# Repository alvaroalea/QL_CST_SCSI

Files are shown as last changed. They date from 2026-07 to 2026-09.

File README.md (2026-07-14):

# CST SCSI/FLOPPY CONTROLLER for Sinclar QL

A clone of the CST's Floppy + hardisc Interface for the Sinclair QL

# WARNING: DO NOT USE THIS PROJECT IS NOT TESTED AND MISSING THINGS

An evolution of the CST V4 Floppy interface with the incorporation of SCSI Controller.

The SCSI was limited only to a especific HDD model: Rodine RO652 20Mb, an UK Manufactured HDD that was also used on Macintosh SE

Later this interface will be use as a base for the Thor 20 Computer SCSI interface.

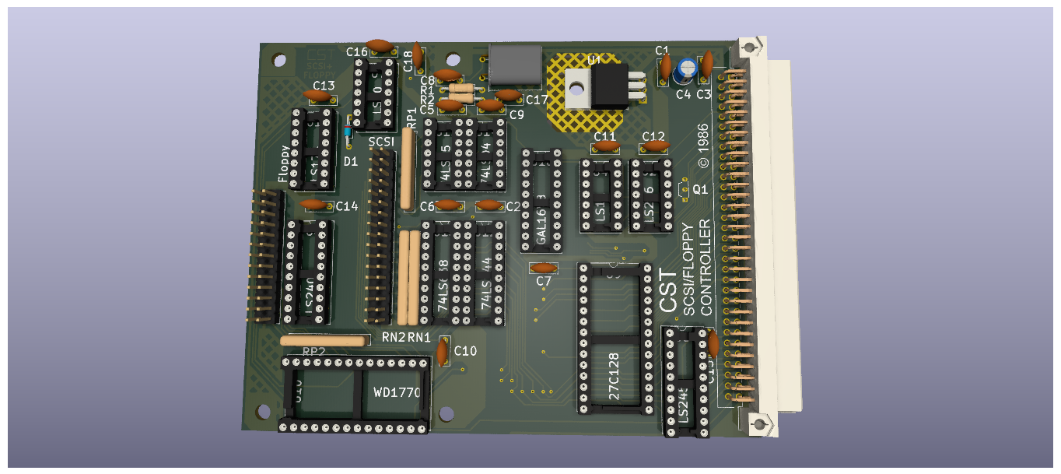
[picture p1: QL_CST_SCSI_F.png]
 

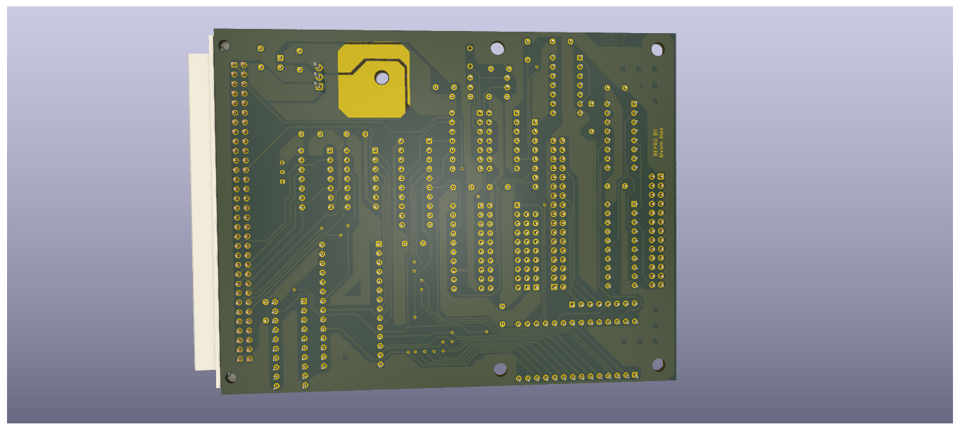
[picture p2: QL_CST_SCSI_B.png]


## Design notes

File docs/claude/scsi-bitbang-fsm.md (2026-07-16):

# Máquina de estados SCSI-1 para bitbanging (iniciador único, sin ATN)

## 1. Fases del bus (nivel alto)

El iniciador reconoce la fase leyendo las líneas **C/D, I/O, MSG** que el
target pone estables justo antes/durante REQ. No hay arbitraje porque eres
el único iniciador en el bus.

```mermaid
stateDiagram-v2
    [*] --> BUS_FREE

    BUS_FREE --> SELECTION: Iniciador quiere mandar comando

    state SELECTION {
        [*] --> SEL_ASSERT
        SEL_ASSERT --> SEL_WAIT_BSY: Pon ID_iniciador+ID_target en DB,\nafirma SEL (sin ATN)
        SEL_WAIT_BSY --> SEL_OK: Target afirma BSY (timeout ~250ms)
        SEL_WAIT_BSY --> SEL_TIMEOUT: No responde
    }
    SELECTION --> BUS_FREE: SEL_TIMEOUT (disco no responde)
    SELECTION --> COMMAND: SEL_OK\n(suelta SEL cuando BSY activo)

    COMMAND --> COMMAND: Handshake REQ/ACK\n(6 bytes del CDB, C/D=1,I/O=0,MSG=0)

    COMMAND --> DATA_IN: si comando de lectura,\ntarget cambia C/D=0,I/O=1
    COMMAND --> DATA_OUT: si comando de escritura,\ntarget cambia C/D=0,I/O=0
    COMMAND --> STATUS: si comando sin datos\n(TEST UNIT READY, START STOP)
    COMMAND --> STATUS: si target reporta error\n(CHECK CONDITION inmediato)

    DATA_IN --> DATA_IN: Handshake REQ/ACK\n(N bytes, target->iniciador)
    DATA_OUT --> DATA_OUT: Handshake REQ/ACK\n(N bytes, iniciador->target)

    DATA_IN --> STATUS: Todos los bytes transferidos\n(C/D=1,I/O=1,MSG=0)
    DATA_OUT --> STATUS: Todos los bytes transferidos

    STATUS --> STATUS: Handshake REQ/ACK\n(1 byte: GOOD=0x00 / CHECK_COND=0x02)

    STATUS --> MSG_IN: target cambia\nC/D=1,I/O=1,MSG=1

    MSG_IN --> MSG_IN: Handshake REQ/ACK\n(1 byte: COMMAND COMPLETE=0x00)

    MSG_IN --> BUS_FREE: Target suelta BSY\n(fin de comando)

    STATUS --> REQUEST_SENSE_NEEDED: si status fue CHECK_CONDITION
    REQUEST_SENSE_NEEDED --> BUS_FREE: (tras MSG_IN)\nlanzar REQUEST SENSE\ncomo nuevo comando
```

**Notas clave:**
- Sin ATN afirmado en SELECTION, el target no espera MESSAGE OUT (te ahorras esa fase).
- El iniciador **nunca decide la fase**: solo la lee de C/D/I-O/MSG y actúa en consecuencia. Si el firmware ve una fase inesperada, debe abortar (soltar el bus, hacer RST si hace falta).
- `REQUEST_SENSE_NEEDED`: tras cualquier `CHECK CONDITION`, el siguiente comando *debe* ser `REQUEST SENSE` o el disco se queda "atascado" en esa condición de error.

---

## 2. Handshake REQ/ACK (el que se ejecuta por cada byte, en cualquier fase)

Es un protocolo **asíncrono** — no hay reloj, todo se sincroniza a mano con
REQ/ACK. Es idéntico en estructura para las 4 fases de transferencia
(COMMAND, DATA, STATUS, MESSAGE IN); solo cambia quién conduce el bus de
datos.

### 2a. Target → Iniciador (DATA IN, STATUS, MESSAGE IN)

```mermaid
stateDiagram-v2
    [*] --> WAIT_REQ_HIGH
    WAIT_REQ_HIGH --> READ_DATA: REQ afirmado por target\n(target ya puso byte válido en DB)
    READ_DATA --> ASSERT_ACK: Iniciador lee DB\n(digitalRead x8, o puerto entero)
    ASSERT_ACK --> WAIT_REQ_LOW: Iniciador afirma ACK
    WAIT_REQ_LOW --> DEASSERT_ACK: Target ve ACK,\ndeasfirma REQ (retira dato)
    DEASSERT_ACK --> WAIT_REQ_HIGH: Iniciador deasfirma ACK\n(byte completo, incrementa contador)
    WAIT_REQ_HIGH --> [*]: si contador de bytes\nde la fase = 0 -> fase terminada
```

### 2b. Iniciador → Target (COMMAND, DATA OUT)

```mermaid
stateDiagram-v2
    [*] --> WAIT_REQ_HIGH
    WAIT_REQ_HIGH --> DRIVE_DATA: REQ afirmado por target\n(target listo para recibir)
    DRIVE_DATA --> ASSERT_ACK: Iniciador pone byte en DB\n(configura puerto como salida)
    ASSERT_ACK --> WAIT_REQ_LOW: Iniciador afirma ACK
    WAIT_REQ_LOW --> RELEASE_DATA: Target latchea el dato,\ndeasfirma REQ
    RELEASE_DATA --> DEASSERT_ACK: Iniciador suelta DB\n(vuelve a alta impedancia / entrada)
    DEASSERT_ACK --> WAIT_REQ_HIGH: Iniciador deasfirma ACK
    WAIT_REQ_HIGH --> [*]: si contador de bytes\nde la fase = 0 -> fase terminada
```

**Timing crítico a respetar en el bitbang (SCSI-1 async, cable corto):**
- Data setup time antes de ACK: ≥ 90 ns (en la práctica, con GPIO de 8 bits a través de un pin-change, ni lo notarás — el cuello de botella real es tu velocidad de toggling de pines).
- Bus settle / skew entre líneas de datos: ≥ 10 ns.
- Ninguno de estos plazos es alcanzable "por accidente" en un micro de 8 bits a decenas de MHz sin cuidado — en la práctica te sobra margen, el problema real suele ser la *capacitancia del cable* si no usas buffers (74LS641 o similar) entre el micro y el bus SCSI de 5V.

---

## 3. Pseudocódigo del bucle central

```c
uint8_t scsi_handshake_in(void) {           // target -> iniciador
    while (!REQ_asserted());                 // espera REQ
    uint8_t byte = read_data_bus();
    ACK_assert();
    while (REQ_asserted());                  // espera a que target suelte REQ
    ACK_deassert();
    return byte;
}

void scsi_handshake_out(uint8_t byte) {      // iniciador -> target
    while (!REQ_asserted());
    drive_data_bus(byte);
    ACK_assert();
    while (REQ_asserted());
    release_data_bus();
    ACK_deassert();
}
```

Con estas dos funciones (`scsi_handshake_in` / `scsi_handshake_out`) y la
máquina de fases de arriba, ya tienes toda la lógica de bajo nivel que
necesita READ(6)/WRITE(6)/STATUS/MESSAGE — cada fase es solo "llamar N
veces a la función correcta".

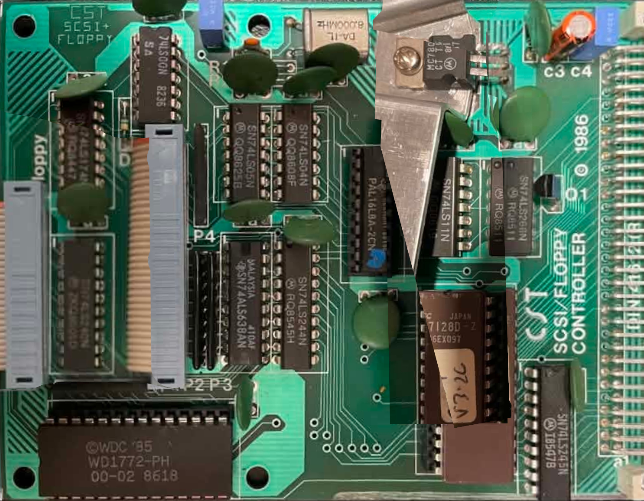
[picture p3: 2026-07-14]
docs/comp.jpg

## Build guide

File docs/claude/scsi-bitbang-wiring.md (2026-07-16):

# Mapeo físico y esquema eléctrico: Arduino Leonardo ↔ 74LS638 / 74LS04 / 74LS06 ↔ SCSI-1 (RO652A)

## 1. Reparto de chips

- **U1 — 74LS638:** bus de datos DB0-DB7 (el único bidireccional).
- **U2 — 74LS04** (inversor hex, push-pull estándar, 6 puertas): las 5
  señales que solo *lees* del SCSI: BSY, REQ, C/D, I/O, MSG. Sobra
  1 puerta libre. Push-pull es válido aquí porque la salida de cada
  puerta solo alimenta una entrada de alta impedancia del Arduino —
  nadie más conduce esa línea, así que no hay competencia eléctrica
  posible. De hecho es preferible al 74LS05: sin pull-ups externos y
  con flancos más rápidos y limpios, mejor para la línea REQ que
  dispara la interrupción.
- **U3 — 74LS06** (inversor hex, colector abierto, 40 mA, 6 puertas):
  las 3 señales que solo *escribes* hacia el SCSI: SEL, ACK, RST.
  Sobran 3 puertas libres.

Al ser inversores simples (sin DIR/OE), aquí no hay nada que
configurar por cableado: cada señal SCSI pasa por una puerta y ya
está.

⚠️ La regla que **no** se puede relajar es la del lado de salida
(U3): ahí sí tiene que ser colector abierto obligatoriamente, porque
esa puerta compite eléctricamente con el pull-up del terminador del
bus (y potencialmente con el propio disco). Un push-pull ahí forzaría
la línea y podría dañar el chip o el disco.

Polaridad resultante (igual criterio que con el 638): como ambos
chips son inversores y las líneas SCSI son activas-en-bajo, en el
lado Arduino "asertado" siempre se lee/escribe como **HIGH** — misma
convención que ya usa el pseudocódigo de la ISR.

**Nota sobre paridad (DBP):** para mantenerlo simple, este diseño **no
implementa el bit de paridad**. El RO652A permite en muchos casos
desactivar la comprobación de paridad por configuración; si tu unidad
concreta la exige, tendrías que añadir un noveno canal (usar un canal
libre de U1 con un XOR de 8 entradas externo, o un segundo 638 de un
solo canal). Verifícalo en la práctica: si el drive devuelve
`CHECK CONDITION` con `PARITY ERROR` en el sense, hay que añadirlo.

---

## 2. Cableado de cada chip

### U1 — 74LS638 (datos, 20 pines)

```
              74LS638 (U1 - DATA, DIR dinámico)
        +--------------------------------+
   DIR--|1                             20|--VCC (+5V)
 SCSI DB0--|2  A1                    B1  19|--Arduino DATA0
 SCSI DB1--|3  A2                    B2  18|--Arduino DATA1
 SCSI DB2--|4  A3                    B3  17|--Arduino DATA2
 SCSI DB3--|5  A4                    B4  16|--Arduino DATA3
 SCSI DB4--|6  A5                    B5  15|--Arduino DATA4
 SCSI DB5--|7  A6                    B6  14|--Arduino DATA5
 SCSI DB6--|8  A7                    B7  13|--Arduino DATA6
 SCSI DB7--|9  A8                    B8  12|--Arduino DATA7
       GND--|10                       OE 11|--GND (siempre habilitado)
        +--------------------------------+
```

### U2 — 74LS04 (entradas, 14 pines, push-pull)

Pinout estándar de la familia 74LSx4/x5/x6 (idéntico al 7404):

```
              74LS04 (U2 - CONTROL-IN)
        +----------------+
   BSY--|1  1A      1Y  2|--> Arduino D10
   REQ--|3  2A      2Y  4|--> Arduino D0   (INT0)
   C/D--|5  3A      3Y  6|--> Arduino A0
   GND--|7               |
   MSG--|9  4A      4Y  8|--> Arduino D13
   I/O--|11 5A      5Y 10|--> Arduino A1
        |   6A      6Y 12|--  libre (spare)
        |13             14|--VCC (+5V)
        +----------------+
```

(Numeración de pines: 1A/1Y=1,2 · 2A/2Y=3,4 · 3A/3Y=5,6 · GND=7 ·
4Y/4A=8,9 · 5Y/5A=10,11 · 6Y/6A=12,13 · VCC=14.)

**Sin pull-ups necesarios:** al ser push-pull, cada salida de U2 ya
conduce activamente tanto a HIGH como a LOW — no hace falta
resistencia externa ni `INPUT_PULLUP` en el Arduino. En firmware, usa
simplemente:
```c
pinMode(PIN_BSY, INPUT);
pinMode(PIN_REQ, INPUT);
pinMode(PIN_CD,  INPUT);
pinMode(PIN_MSG, INPUT);
pinMode(PIN_IO,  INPUT);
```

### U3 — 74LS06 (salidas, 14 pines, colector abierto, 40 mA)

Mismo pinout físico que el 74LS04 (familia idéntica):

```
              74LS06 (U3 - CONTROL-OUT)
        +----------------+
   SEL--|1  1A      1Y  2|--< Arduino A2
   ACK--|3  2A      2Y  4|--< Arduino D11
   RST--|5  3A      3Y  6|--< Arduino D12
   GND--|7               |
        |9  4A      4Y  8|--  libre (spare)
        |11 5A      5Y 10|--  libre (spare)
        |   6A      6Y 12|--  libre (spare)
        |13             14|--VCC (+5V)
        +----------------+
```

Aquí NO hace falta pull-up en ningún lado: el lado SCSI (pines 1,3,5)
ya está tirado a +5V por el terminador del bus, y el lado Arduino
(pines 2,4,6) lo maneja el propio Arduino en push-pull normal, sin
necesitar resistencia.

**Desacoplo:** un condensador cerámico de 100 nF entre VCC y GND lo más
cerca posible de cada chip (pines 20/10), imprescindible en los tres.

---

## 3. Terminación del bus SCSI

El RO652A trae **packs de resistencias terminadoras** en la propia
placa (se ve en la serigrafía de la hoja de specs). SCSI exige
terminación en **ambos extremos físicos** del bus:

- **Extremo del disco:** deja puesto (o vuelve a poner) su pack
  terminador — el RO652 casi siempre se vende con el jumper/pack de
  terminación instalado de fábrica al ser normalmente el único
  dispositivo interno de un Mac/PC de la época.
- **Extremo del Arduino (tu "host adapter"):** necesitas añadir tú un
  terminador pasivo, típicamente un pack SIP de 220 Ω a TERMPWR (+5V)
  y 330 Ω a GND por cada línea de señal (18 líneas: 8 datos + paridad
  + 9 de control). Existen packs comerciales listos (p.ej.
  "9-line SCSI terminator resistor pack").
- **TERMPWR (pin 26):** alguien tiene que alimentarlo con +5V a través
  de un diodo (típicamente 1N5817) y un fusible/polyfuse de ~0.5-1A.
  Si el disco ya lo suministra (frecuente en unidades con terminador
  activo de fábrica), no hace falta que lo hagas también desde el
  Arduino — comprueba con un multímetro si el pin 26 ya tiene +5V
  antes de conectar tu propia fuente, para no pelear dos fuentes entre sí.

Dado que a las velocidades async de bitbang y con un cable corto
punto-a-punto el margen es muy generoso, un terminador algo
imperfecto probablemente "funcione" en pruebas de banco — pero seguir
la terminación en ambos extremos evita reflejos que pueden manifestarse
como bytes corruptos intermitentes, difíciles de diagnosticar.

---

## 4. Mapeo de pines: Arduino Leonardo ↔ 74LS638 ↔ conector SCSI-1 (50 pin IDC)

El RO652A es un drive interno con conector de 50 pines (2×25, paso
0.1"). Pinout estándar SCSI-1 de un solo extremo (single-ended):

| Pin | Señal | Pin | Señal |
|-----|---|-----|---|
| 1 | GND | 2 | -DB0  |
| 3 | GND | 4 | -DB1  |
| 5 | GND | 6 | -DB2  |
| 7 | GND | 8 | -DB3  |
| 9 | GND | 10  | -DB4  |
| 11  | GND | 12  | -DB5  |
| 13  | GND | 14  | -DB6  |
| 15  | GND | 16  | -DB7  |
| 17  | GND | 18  | -DBP (paridad) |
| 19  | GND | 20  | GND |
| 21  | GND | 22  | GND |
| 23  | reservado | 24 | reservado |
| 25  | abierto (no usar) | 26 | TERMPWR (+5V) |
| 27  | reservado | 28 | reservado |
| 29  | GND | 30  | GND |
| 31  | GND | 32  | -ATN  |
| 33  | GND | 34  | GND |
| 35  | GND | 36  | -BSY  |
| 37  | GND | 38  | -ACK  |
| 39  | GND | 40  | -RST  |
| 41  | GND | 42  | -MSG  |
| 43  | GND | 44  | -C/D  |
| 45  | GND | 46  | -REQ  |
| 47  | GND | 48  | -I/O  |
| 49  | GND | 50  | -SEL  |

Todas las señales son activas-en-bajo (negative-true). Los pines
impares son mayoritariamente GND — esto es intencional en el diseño
del cable: cada línea de señal va emparejada con un retorno de tierra
adyacente para reducir diafonía/reflejos.

### Tabla de conexión completa

| Señal SCSI | Pin conector | Chip / puerta | Pin Arduino Leonardo | Notas |
|---|---|---|---|---|
| DB0 | 2  | U1.A1 / U1.B1 | D2  | Bus de datos |
| DB1 | 4  | U1.A2 / U1.B2 | D3  | |
| DB2 | 6  | U1.A3 / U1.B3 | D4  | |
| DB3 | 8  | U1.A4 / U1.B4 | D5  | |
| DB4 | 10 | U1.A5 / U1.B5 | D6  | |
| DB5 | 12 | U1.A6 / U1.B6 | D7  | |
| DB6 | 14 | U1.A7 / U1.B7 | D8  | |
| DB7 | 16 | U1.A8 / U1.B8 | D9  | |
| DBP | 18 | — | — | no implementada (ver nota de paridad) |
| BSY | 36 | U2 (74LS04) gate 1 | D10 | solo lectura |
| ACK | 38 | U3 (74LS06) gate 1 | D11 | solo escritura |
| RST | 40 | U3 (74LS06) gate 2 | D12 | solo escritura |
| MSG | 42 | U2 (74LS04) gate 4 | D13 | solo lectura |
| C/D | 44 | U2 (74LS04) gate 3 | A0  | solo lectura |
| REQ | 46 | U2 (74LS04) gate 2 | **D0** (INT0) | **interrupción**, flancos limpios sin pull-up |
| I/O | 48 | U2 (74LS04) gate 5 | A1  | solo lectura |
| SEL | 50 | U3 (74LS06) gate 3 | A2  | solo escritura |
| U1.DIR | — | — | A3  | control dinámico dirección datos |

**Por qué REQ en D0:** en el Leonardo (ATmega32u4), las únicas líneas
con interrupción externa "de verdad" (`INT`) son D0, D1, D2, D3 y D7
— cualquiera de ellas vale para `attachInterrupt(..., CHANGE)`. Elegí
D0 porque queda libre de otros usos (D1/D2/D3 en muchos Leonardo
también sirven de I2C/Serial1, mejor dejarlos libres por si los
necesitas para depuración por el monitor serie).

**TERMPWR (pin 26):** solo conéctalo a tu +5V si compruebas que el
disco no lo está ya suministrando (ver sección 3).

**GND:** conecta varios de los pines GND del conector (p.ej. 1, 3, 5,
20, 41, 49) a la masa común de tu placa — no hace falta cablear los 25,
pero sí varios repartidos para un buen retorno de corriente.

---

## 5. Resumen de asignación de pines en el Leonardo

```
D0  -> REQ   (INT0, entrada)
D1  -> (libre, reservado para Serial1 TX si lo necesitas)
D2  -> DB0
D3  -> DB1
D4  -> DB2
D5  -> DB3
D6  -> DB4
D7  -> DB5
D8  -> DB6
D9  -> DB7
D10 -> BSY   (entrada)
D11 -> ACK   (salida)
D12 -> RST   (salida)
D13 -> MSG   (entrada)   // ojo: D13 tiene el LED integrado, no afecta
                          // funcionalmente pero parpadeará con MSG
A0  -> C/D   (entrada)
A1  -> I/O   (entrada)
A2  -> SEL   (salida)
A3  -> DIR del U1 (salida)
```

Con esto tienes wiring completo y coherente con el pseudocódigo de la
ISR de la sección anterior (`PIN_REQ=D0`, `PIN_ACK=D11`, etc. — solo
falta actualizar las constantes `#define` del firmware con estos
números de pin reales).

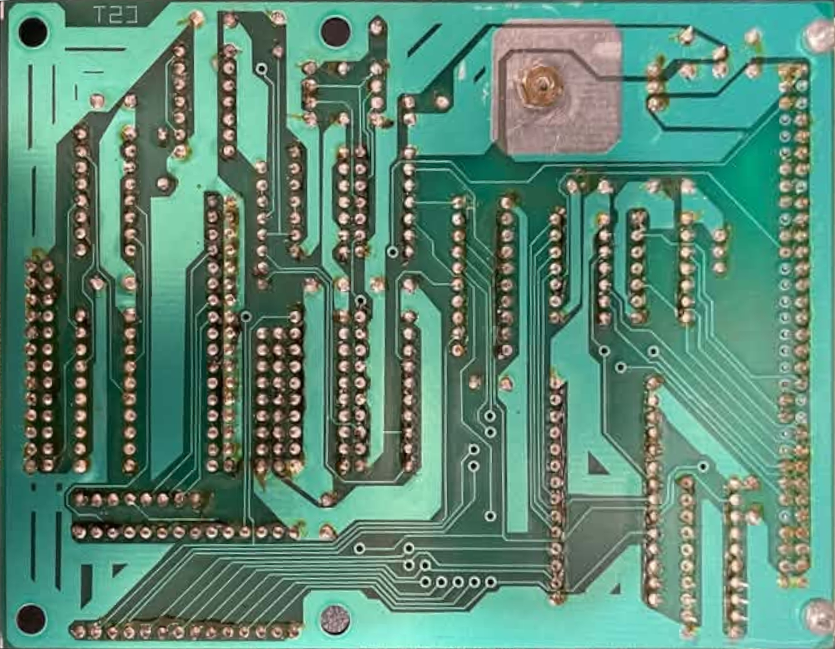
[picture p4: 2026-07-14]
docs/solder.jpg

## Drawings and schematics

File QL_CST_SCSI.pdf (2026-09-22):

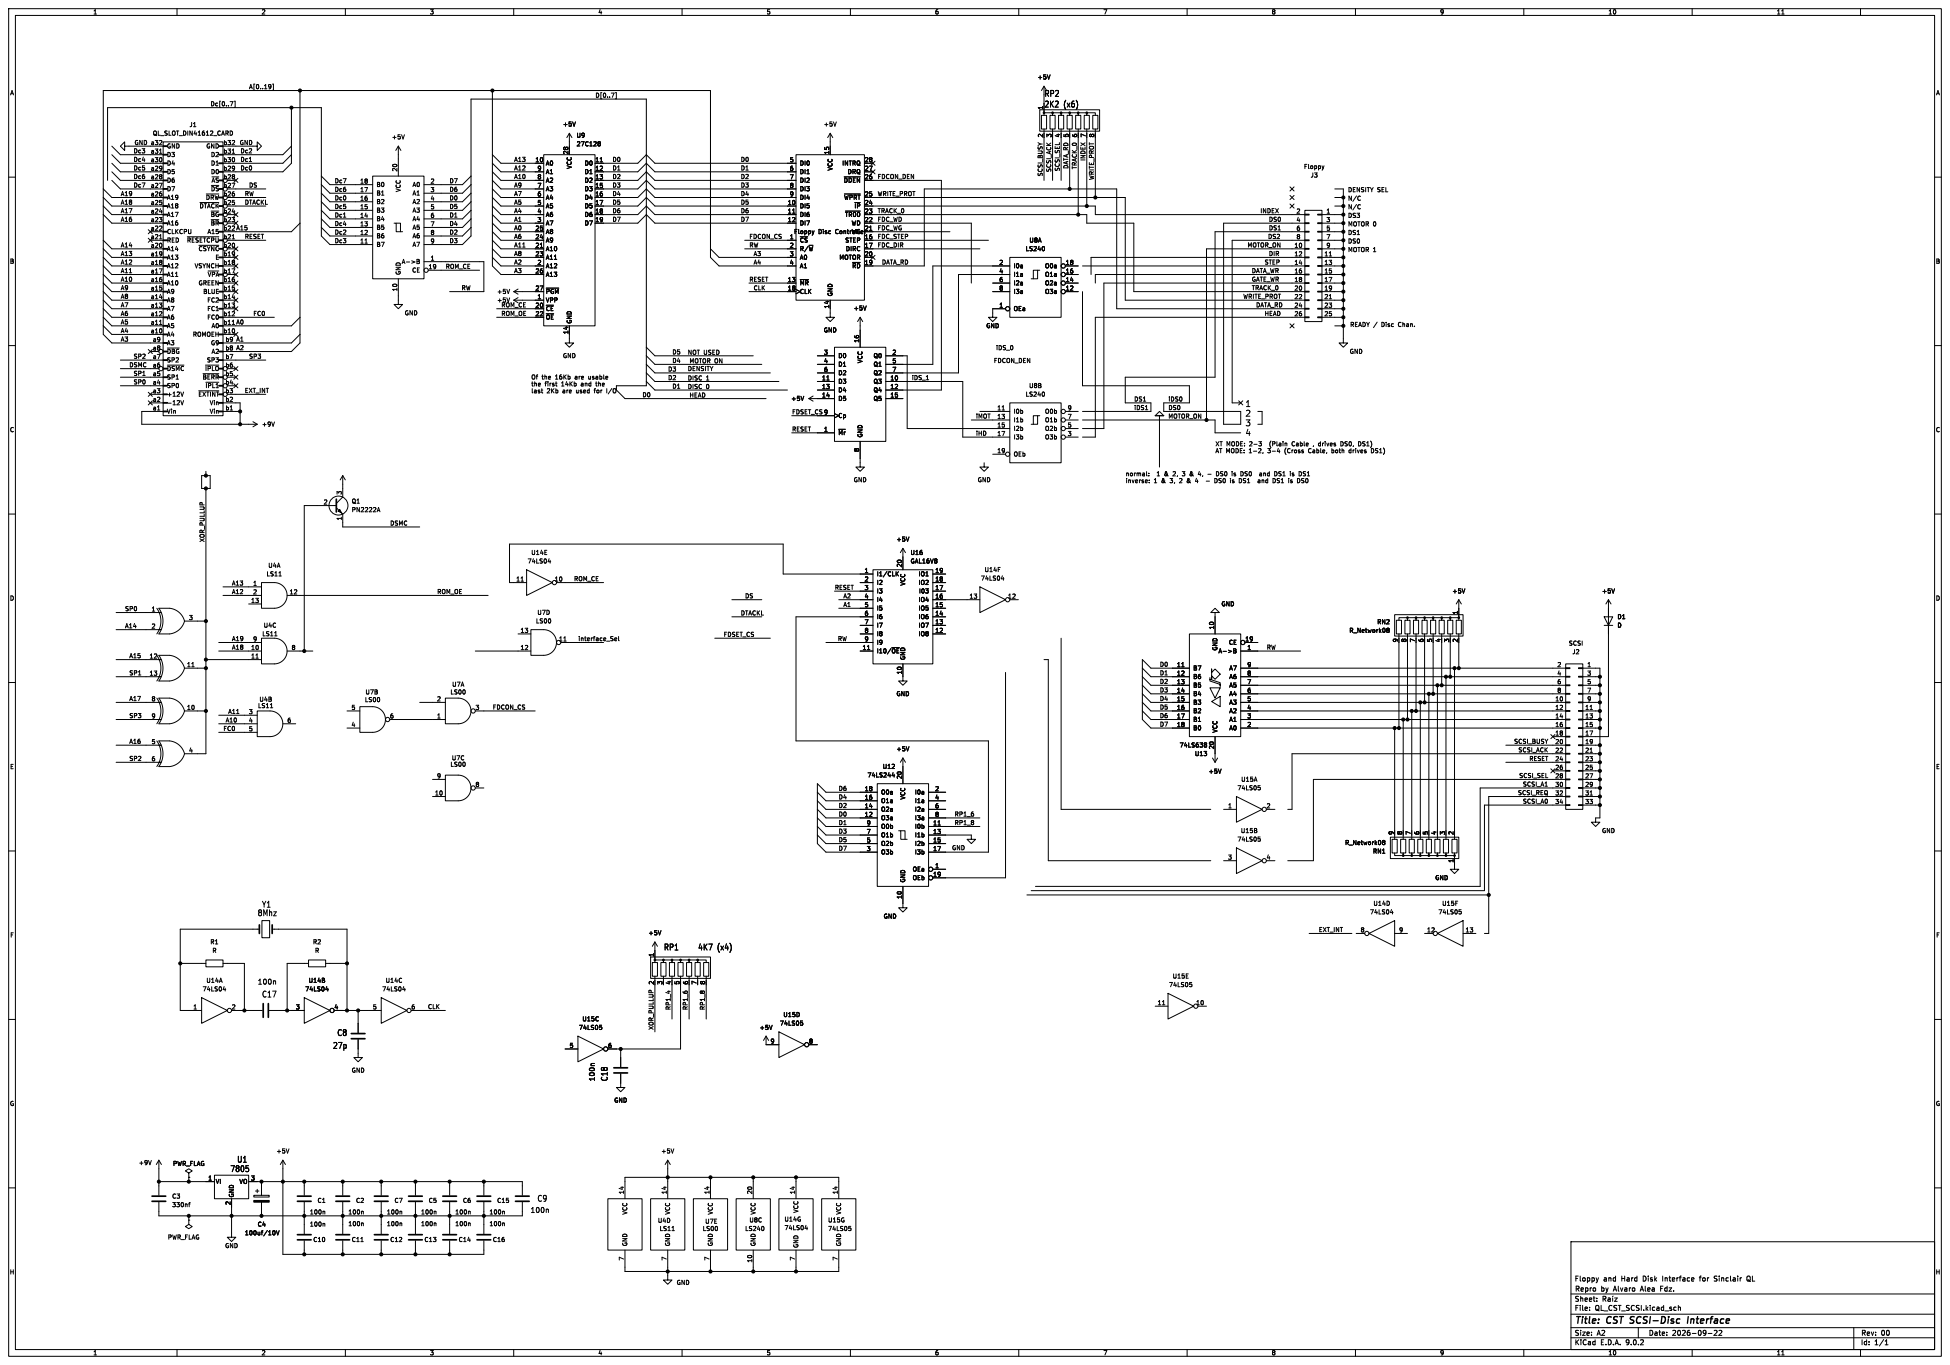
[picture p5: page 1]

2K2 (x6) GND a32 D3 a31 D4 a30 D5 a29 D6 a28 D7 a27 A19 a26 A18 a25 A17 a24 A16 a23 CLKCPU a22 RED a21 A14 a20 A13 a19 A12 a18 A11 a17 A10 a16 A9 a15 A8 a14 A7 a13 A6 a12 A5 a11 A4 a10 A3 a9 ~{DBG} a8 SP2 a7 ~{DSMC} a6 SP1 a5 SP0 a4 +12V a3

FDCON_CS D1 D0 D3 D2
INTRQ 28 DRQ 27 ~{DDEN}26 ~{WPRT}25 ~{IP}24 ~{TR00}23 WD 22 WG 21 STEP 16 DIRC 17 MOTOR 20 ~{RD}19 +5V GND

8 Q0 2 Q1 5 Q2 7 Q3 10 Q4 12 Q5 15 DI0 5 DI1 6 DI2 7 DI3 8 DI4 9 DI5 10 DI6 11 DI7 12 ~{CS} 1 R/~{W} 2 A0 3 A1 4 ~{MR} 13 CLK 18 VCC 15 GND 14

J3 Floppy
DENSITY SEL READY / Disc Chan. N/C

b19 VSYNCH b18 ~{VPA}b17 GREEN b16 BLUE b15 FC2 b14 FC1 b13 FC0 b12 A0 b11 ROMOEH b10 G9 b9 A2 b8 SP3 b7 ~{IPLO}b6 ~{BERR}b5 ~{IPL1}b4 ~{EXTINT}b3 Vin b2 Vin b1

the first 14Kb and the
last 2Kb are used for I/O

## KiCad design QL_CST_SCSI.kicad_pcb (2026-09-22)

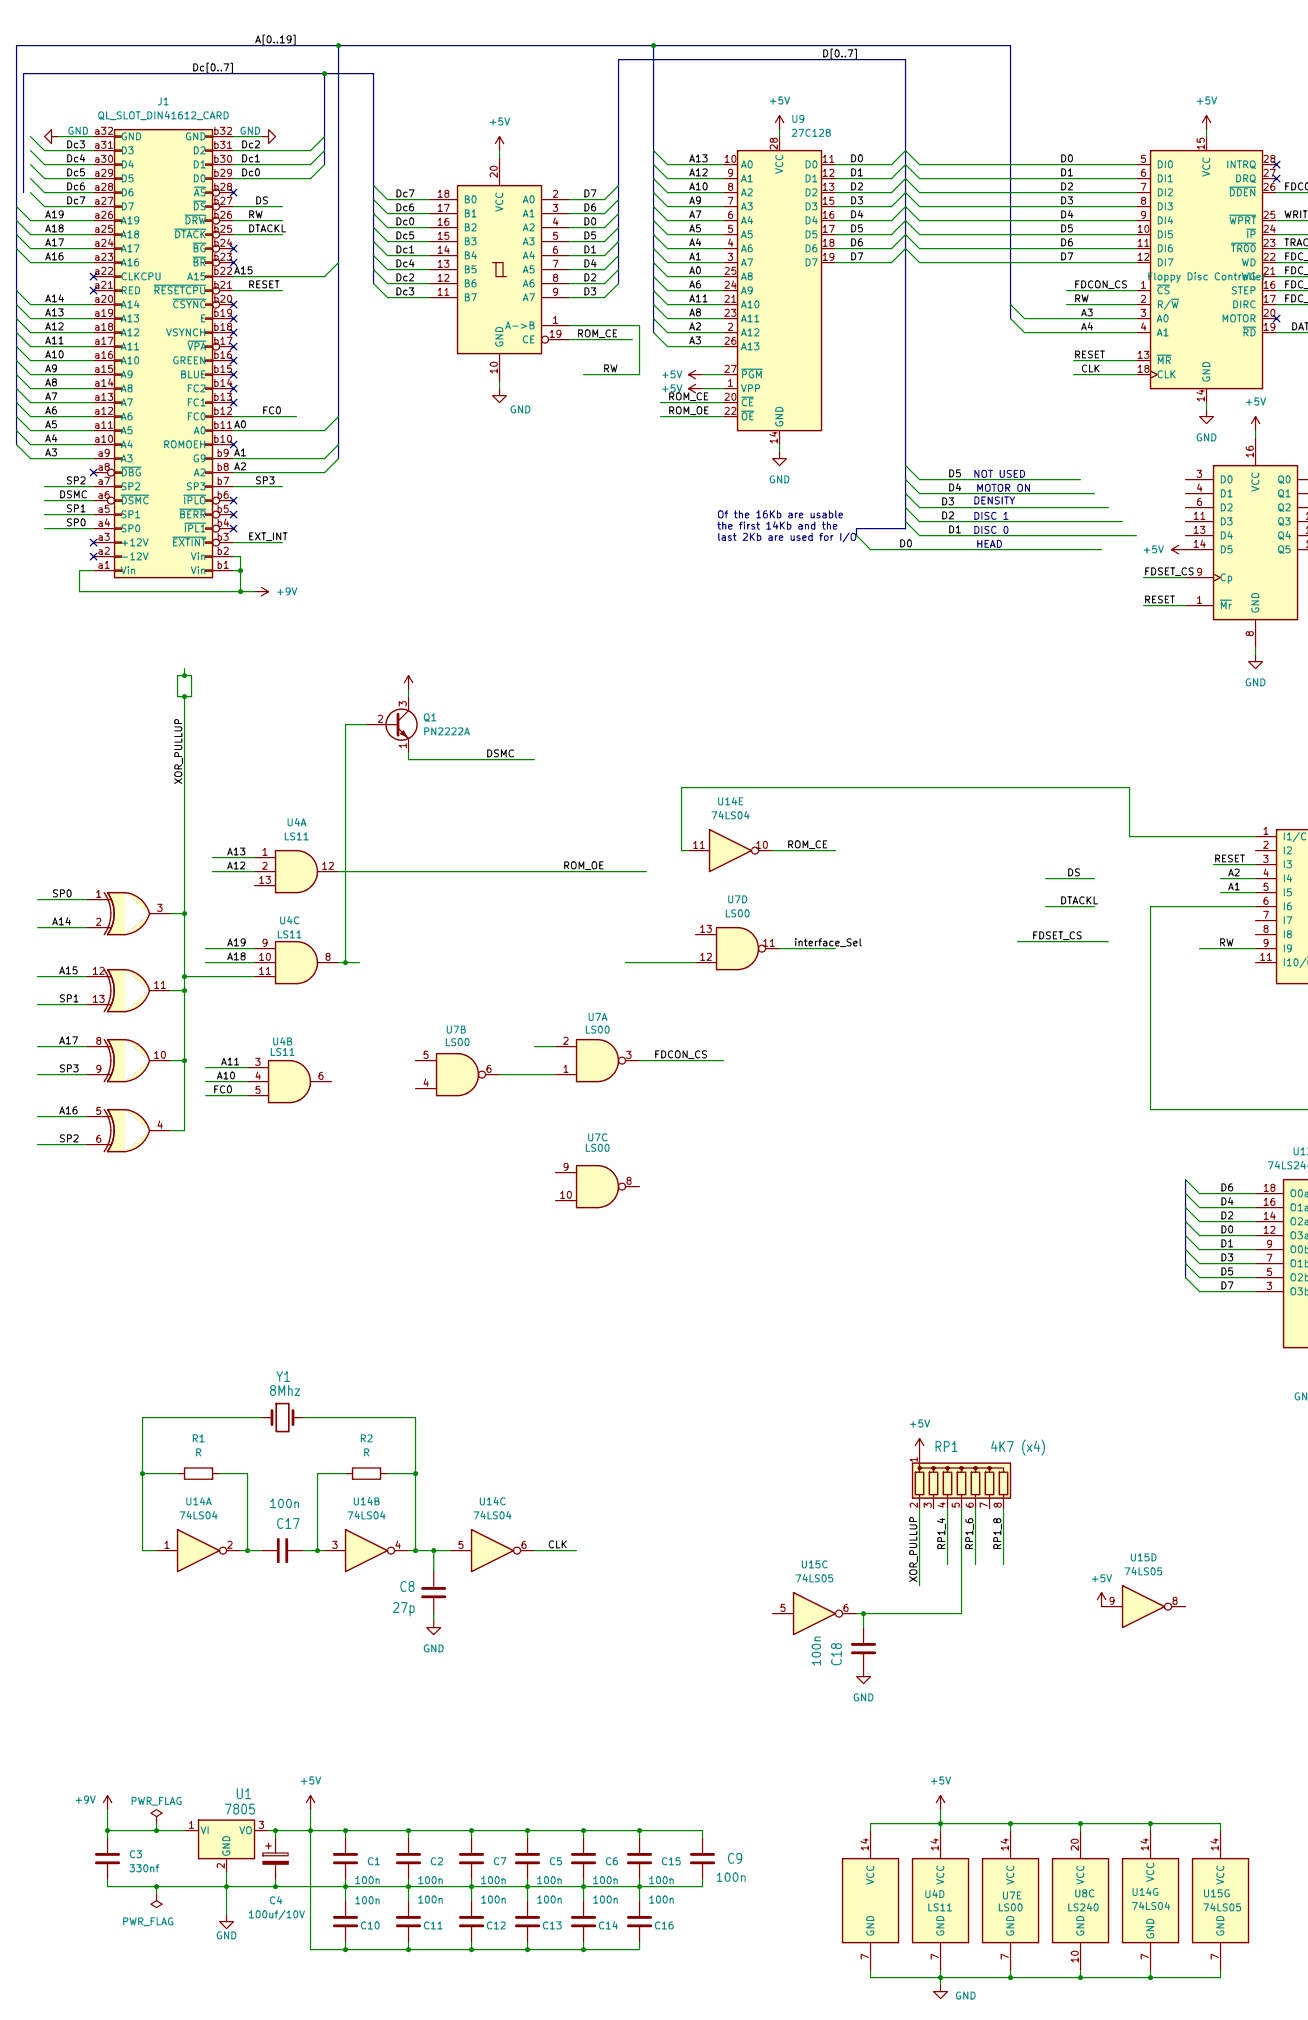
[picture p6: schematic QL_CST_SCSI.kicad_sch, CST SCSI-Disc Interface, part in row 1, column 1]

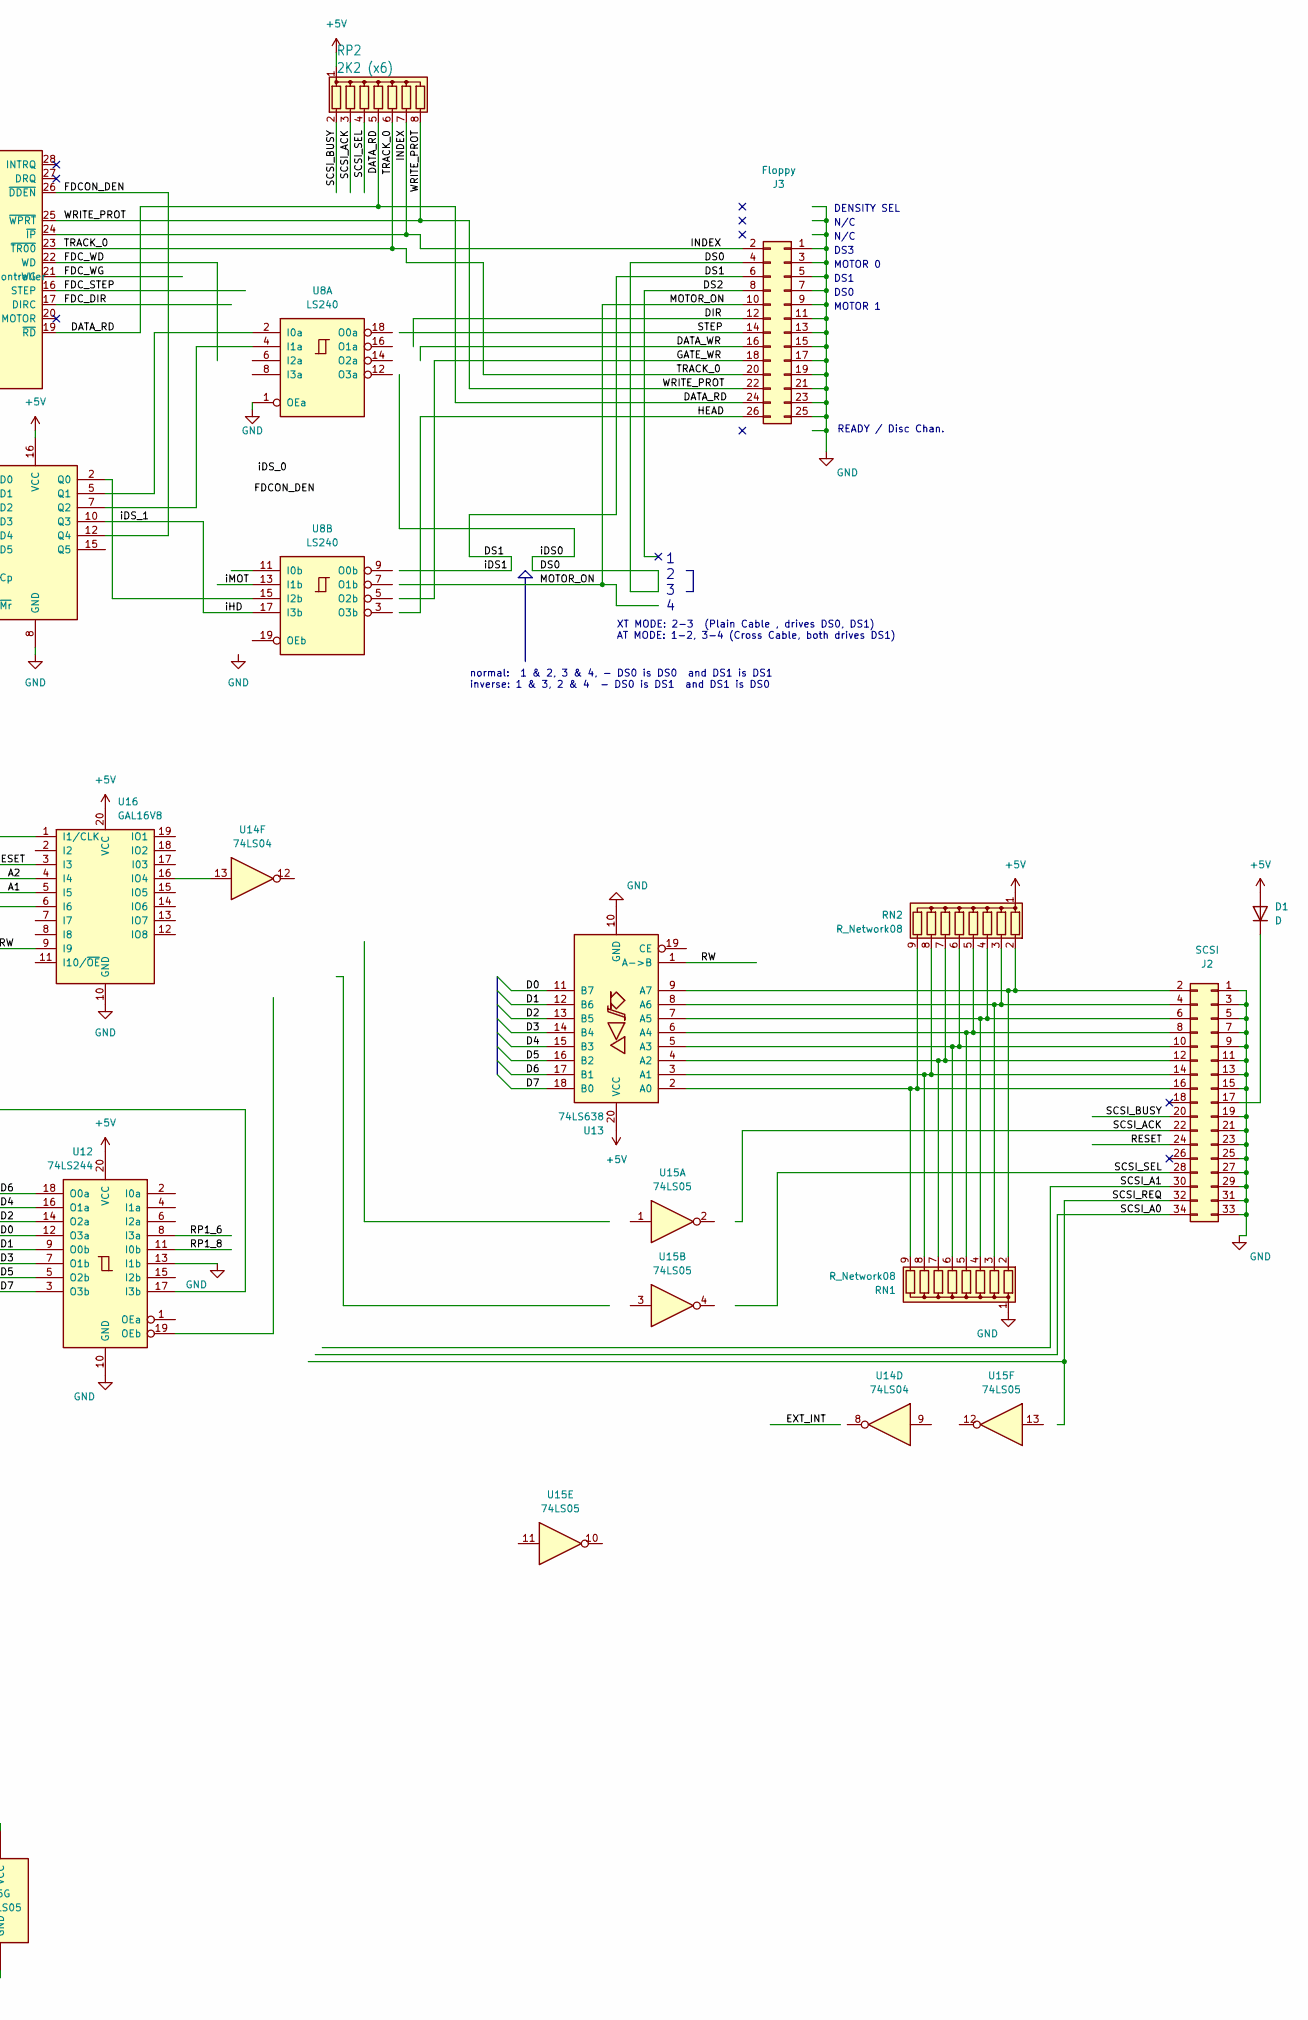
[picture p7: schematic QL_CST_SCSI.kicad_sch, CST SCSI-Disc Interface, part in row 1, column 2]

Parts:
C1, C2, C5, C6, C7, C9, C10, C11, C12, C13, C14, C15, C16, C17, C18: 100n; C_Disc_D7.0mm_W2.5mm_P5.00mm
C3: 330nf; C_Disc_D7.0mm_W2.5mm_P5.00mm
C4: 100uf/10V; CP_Radial_D5.0mm_P2.50mm
C8: 27p; C_Disc_D7.0mm_W2.5mm_P5.00mm
D1: D; D_DO-34_SOD68_P7.62mm_Horizontal
J1: QL_SLOT_DIN41612_CARD; DIN41612_B_2x32_Female_Horizontal_THT
J2: SCSI; PinHeader_2x17_P2.54mm_Vertical
J3: Floppy; PinHeader_2x13_P2.54mm_Vertical
Q1: PN2222A; TO-92S_Wide
R1, R2: R; R_Axial_DIN0207_L6.3mm_D2.5mm_P10.16mm_Horizontal
RN1, RN2: R_Network08; R_Array_SIP9
RP1: 4K7 (x4); R_Array_SIP8
RP2: 2K2 (x6); R_Array_SIP8
U1: 7805; TO-220-3_Horizontal_TabDown
U2: LS266; DIP-14_W7.62mm_Socket
U4: LS11; DIP-14_W7.62mm_Socket
U5: LS245; DIP-20_W7.62mm_Socket
U7: LS00; DIP-14_W7.62mm_Socket
U8: LS240; DIP-20_W7.62mm_Socket
U9: 27C128; DIP-28_W15.24mm_Socket
U10: WD1770; DIP-28_W15.24mm_Socket
U11: LS174; DIP-16_W7.62mm_Socket
U12: 74LS244; DIP-20_W7.62mm_Socket
U13: 74LS638; DIP-20_W7.62mm_Socket
U14: 74LS04; DIP-14_W7.62mm_Socket
U15: 74LS05; DIP-14_W7.62mm_Socket
U16: GAL16V8; DIP-20_W7.62mm_Socket
Y1: 8Mhz; Crystal_HC18-U_Horizontal

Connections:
+5V: C1.1, C2.1, C4.1, C5.1, C6.1, C7.1, C9.2, C10.1, C11.1, C12.1, C13.1, C14.1, C15.1, C16.1, D1.2 (A), Q1.3 (C), RN2.1 (common), RP1.1 (common), RP2.1 (common), U1.3 (VO), U2.14 (VCC), U4.14 (VCC), U5.20 (VCC), U7.14 (VCC), U8.20 (VCC), U9.1 (VPP), U9.27 (~PGM), U9.28 (VCC), U10.15 (VCC), U11.14 (D5), U11.16 (VCC), U12.20 (VCC), U13.20 (VCC), U14.14 (VCC), U15.9, U15.14 (VCC), U16.20 (VCC)
+9V: C3.1, J1.a1 (Vin), J1.b1 (Vin), J1.b2 (Vin), U1.1 (VI)
/A0: J1.b11 (A0), U9.25 (A8)
/A1: J1.b9 (G9), U9.3 (A7), U16.5 (I5)
/A2: J1.b8 (A2), U9.2 (A12), U16.4 (I4)
/A3: J1.a9 (A3), U9.26 (A13), U10.3 (A0)
/A4: J1.a10 (A4), U9.4 (A6), U10.4 (A1)
/A5: J1.a11 (A5), U9.5 (A5)
/A6: J1.a12 (A6), U9.24 (A9)
/A7: J1.a13 (A7), U9.6 (A4)
/A8: J1.a14 (A8), U9.23 (A11)
/A9: J1.a15 (A9), U9.7 (A3)
/A10: J1.a16 (A10), U4.4, U9.8 (A2)
/A11: J1.a17 (A11), U4.3, U9.21 (A10)
/A12: J1.a18 (A12), U4.2, U9.9 (A1)
/A13: J1.a19 (A13), U4.1, U9.10 (A0)
/A14: J1.a20 (A14), U2.2
/A15: J1.b22 (A15), U2.12
/A16: J1.a23 (A16), U2.5
/A17: J1.a24 (A17), U2.8
/A18: J1.a25 (A18), U4.10
/A19: J1.a26 (A19), U4.9
/CLK: U10.18 (CLK), U14.6
/D0: U5.4 (A2), U9.11 (D0), U10.5 (DI0), U12.12 (O3a), U13.11 (B7)
/D1: U5.6 (A4), U9.12 (D1), U10.6 (DI1), U12.9 (O0b), U13.12 (B6)
/D2: U5.8 (A6), U9.13 (D2), U10.7 (DI2), U12.14 (O2a), U13.13 (B5)
/D3: U5.9 (A7), U9.15 (D3), U10.8 (DI3), U12.7 (O1b), U13.14 (B4)
/D4: U5.7 (A5), U9.16 (D4), U10.9 (DI4), U12.16 (O1a), U13.15 (B3)
/D5: U5.5 (A3), U9.17 (D5), U10.10 (DI5), U12.5 (O2b), U13.16 (B2)
/D6: U5.3 (A1), U9.18 (D6), U10.11 (DI6), U12.18 (O0a), U13.17 (B1)
/D7: U5.2 (A0), U9.19 (D7), U10.12 (DI7), U12.3 (O3b), U13.18 (B0)
/DATA_RD: J3.24, RP2.5 (R4), U10.19 (~RD)
/DATA_WR: J3.16
/DIR: J3.12
/DS: J1.b27 (~DS)
/DS0: J3.4
/DS1: J3.6
/DS2: J3.8
/DSMC: J1.a6 (~DSMC), Q1.1 (E)
/DTACKL: J1.b25 (~DTACK)
/Dc0: J1.b29 (D0), U5.16 (B2)
/Dc1: J1.b30 (D1), U5.14 (B4)
/Dc2: J1.b31 (D2), U5.12 (B6)
/Dc3: J1.a31 (D3), U5.11 (B7)
/Dc4: J1.a30 (D4), U5.13 (B5)
/Dc5: J1.a29 (D5), U5.15 (B3)
/Dc6: J1.a28 (D6), U5.17 (B1)
/Dc7: J1.a27 (D7), U5.18 (B0)
/EXT_INT: J1.b3 (~EXTINT)
/FC0: J1.b12 (FC0), U4.5
/FDCON_CS: U7.3, U10.1 (~CS)
/FDCON_DEN: U10.26 (~DDEN), U11.12 (Q4)
/FDC_DIR: U10.17 (DIRC)
/FDC_STEP: U10.16 (STEP)
/FDC_WD: U10.22 (WD)
/FDC_WG: U10.21 (WG)
/FDSET_CS: U11.9 (Cp)
/GATE_WR: J3.18
/HEAD: J3.26
/INDEX: J3.2, RP2.7 (R6), U10.24 (~IP)
/MOTOR_ON: J3.10
/RESET: J1.b21 (~RESETCPU), J2.24, U10.13 (~MR), U11.1 (~Mr), U16.3 (I3)
/ROM_CE: U5.19 (CE), U9.20 (~CE), U14.10
/ROM_OE: U4.12, U9.22 (~OE)
/RP1_4: RP1.4 (R3)
/RP1_6: RP1.6 (R5), U12.8 (I3a)
/RP1_8: RP1.8 (R7), U12.11 (I0b)
/RW: J1.b26 (~DRW), U5.1 (A->B), U10.2 (R/~W), U13.1 (A->B), U16.9 (I9)
/SCSI_A0: J2.34
/SCSI_A1: J2.30
/SCSI_ACK: J2.22, RP2.3 (R2)
/SCSI_BUSY: J2.20, RP2.2 (R1)
/SCSI_REQ: J2.32
/SCSI_SEL: J2.28, RP2.4 (R3)
/SP0: J1.a4 (SP0), U2.1
/SP1: J1.a5 (SP1), U2.13
/SP2: J1.a7 (SP2), U2.6
/SP3: J1.b7 (SP3), U2.9
/STEP: J3.14
/TRACK_0: J3.20, RP2.6 (R5), U10.23 (~TR00)
/WRITE_PROT: J3.22, RP2.8 (R7), U10.25 (~WPRT)
/XOR_PULLUP: RP1.2 (R1), U2.3, U2.4, U2.10, U2.11, U4.11
/iDS_1: U8.17 (I3b), U11.10 (Q3)
/iMOT: U8.13 (I1b)
/interface_Sel: U7.11
GND: C1.2, C2.2, C3.2, C4.2, C5.2, C6.2, C7.2, C8.2, C9.1, C10.2, C11.2, C12.2, C13.2, C14.2, C15.2, C16.2, C18.1, J1.a32 (GND), J1.b32 (GND), J2.1, J2.3, J2.5, J2.7, J2.9, J2.11, J2.13, J2.15, J2.19, J2.21, J2.23, J2.25, J2.27, J2.29, J2.31, J2.33, J3.1, J3.3, J3.5, J3.7, J3.9, J3.11, J3.13, J3.15, J3.17, J3.19, J3.21, J3.23, J3.25, RN1.1 (common), U1.2 (GND), U2.7 (GND), U4.7 (GND), U5.10 (GND), U7.7 (GND), U8.1 (OEa), U8.10 (GND), U9.14 (GND), U10.14 (GND), U11.8 (GND), U12.10 (GND), U12.13 (I1b), U13.10 (GND), U14.7 (GND), U15.7 (GND), U16.10 (GND)
unnamed: C8.1, R2.1, U14.4, U14.5, Y1.2
unnamed: C17.1, R2.2, U14.3
unnamed: C17.2, R1.2, U14.2
unnamed: D1.1 (K), J2.17
unnamed: J2.2, RN1.2 (R1), RN2.2 (R1), U13.9 (A7)
unnamed: J2.4, RN1.3 (R2), RN2.3 (R2), U13.8 (A6)
unnamed: J2.6, RN1.4 (R3), RN2.4 (R3), U13.7 (A5)
unnamed: J2.8, RN1.5 (R4), RN2.5 (R4), U13.6 (A4)
unnamed: J2.10, RN1.6 (R5), RN2.6 (R5), U13.5 (A3)
unnamed: J2.12, RN1.7 (R6), RN2.7 (R6), U13.4 (A2)
unnamed: J2.14, RN1.8 (R7), RN2.8 (R7), U13.3 (A1)
unnamed: J2.16, RN1.9 (R8), RN2.9 (R8), U13.2 (A0)
unnamed: Q1.2 (B), U4.8
unnamed: R1.1, U14.1, Y1.1
unnamed: C18.2, RP1.5 (R4), U15.6
unnamed: U7.1, U7.6
unnamed: U8.15 (I2b), U11.2 (Q0)
unnamed: U8.2 (I0a), U11.5 (Q1)
unnamed: U8.4 (I1a), U11.7 (Q2)
unnamed: U12.17 (I3b), U16.6 (I6)
unnamed: U14.11, U16.1 (I1/CLK)
unnamed: U14.13, U16.16 (IO4)

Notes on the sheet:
XT MODE: 2-3 (Plain Cable , drives DS0, DS1) AT MODE: 1-2, 3-4 (Cross Cable, both drives DS1)
NOT USED
MOTOR ON
MOTOR 0
HEAD
normal: 1 & 2, 3 & 4, - DS0 is DS0 and DS1 is DS1 inverse: 1 & 3, 2 & 4 - DS0 is DS1 and DS1 is DS0
DS0
DS1
READY / Disc Chan.
DENSITY
MOTOR 1
DS3
Of the 16Kb are usable the first 14Kb and the last 2Kb are used for I/O
N/C
1 2 3 4
DISC 1
DENSITY SEL
DISC 0

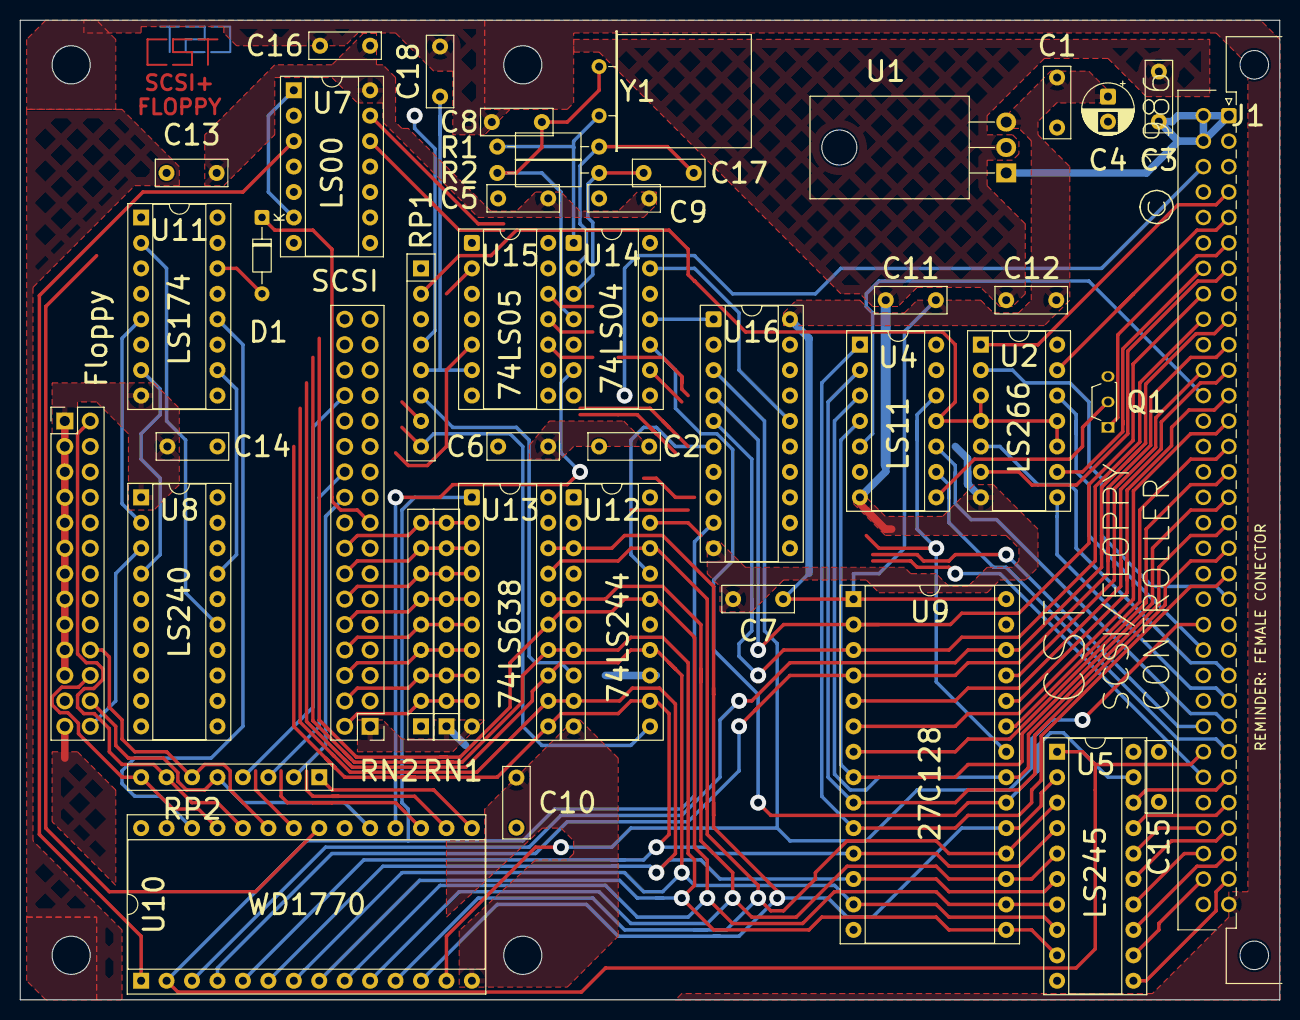
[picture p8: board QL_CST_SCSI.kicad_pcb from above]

Board: 2 copper layers, 125.7 x 97.8 mm, 44 parts (0 on the bottom side), 85 nets.

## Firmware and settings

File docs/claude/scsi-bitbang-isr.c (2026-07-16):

/* =====================================================================
 * SCSI-1 bitbang initiator, dirigido por interrupción en el pin REQ.
 *
 * Idea central:
 *   - La ISR solo hace UN paso del handshake por flanco de REQ.
 *     No bloquea nunca (nada de "while" dentro de la ISR).
 *   - El main loop arma el "contexto de fase" (buffer, longitud,
 *     dirección) y luego espera a que la ISR marque phase_done.
 *   - Antes de cada fase, el main loop LEE C/D, I/O, MSG para saber
 *     qué fase ha puesto el target — nunca se asume la secuencia,
 *     porque el target puede saltar directo a STATUS si hay error.
 * ===================================================================== */

#include <stdint.h>
#include <stdbool.h>

/* ---- Definición de pines (activo-alto lógico; invierte en las
 *      macros si tu bus es activo-bajo físicamente) -------------------- */
#define PIN_REQ   2      // debe ser pin con capacidad de interrupción externa
#define PIN_ACK   3
#define PIN_CD    4
#define PIN_IO    5
#define PIN_MSG   6
#define PIN_BSY   7
#define PIN_SEL   8
#define DATA_PORT PORTD  // puerto de 8 bits para DB0-DB7 (+ paridad si aplica)
#define DATA_DDR  DDRD

#define DIR_IN  0
#define DIR_OUT 1

typedef enum {
    PH_COMMAND, PH_DATA_IN, PH_DATA_OUT, PH_STATUS, PH_MSG_IN
} phase_t;

/* =====================================================================
 * TIMEOUTS calculados a partir de la hoja de specs del RODIME RO652A:
 *   track-to-track 18ms | seek avg 85ms | seek MAX 180ms
 *   latencia rotacional avg 10.9ms (2746 RPM) | buffer FIFO 4KB
 *
 * Dos escalas de tiempo distintas por diseño:
 *   - "primer byte" de una fase DATA: aquí es donde el drive hace el
 *     seek físico + espera de latencia + posible retry interno tras
 *     un error de lectura (ECC). Discos de esta época pueden tardar
 *     varios segundos en un retry interno silencioso.
 *   - "bytes siguientes" una vez ya hay transferencia en curso: el
 *     disco ya está sirviendo desde el buffer FIFO a 0.937 MB/s, así
 *     que el cuello de botella pasa a ser TU propio bitbang, no el
 *     disco. Aquí el timeout solo debe pillar un fallo real de bus.
 * ===================================================================== */
#define TIMEOUT_SELECT_MS        250    // standard SCSI-1 selection timeout

#define TIMEOUT_CMD_FIRST_MS     500    // COMMAND: sin mecánica de por medio,
                                          // margen por si el drive está
                                          // terminando otra operación
#define TIMEOUT_CMD_BYTE_MS       50

#define TIMEOUT_DATA_FIRST_MS   4000    // seek MAX 180ms + latencia + margen
                                          // amplio para retries internos de
                                          // ECC/recalibración (drive viejo)
#define TIMEOUT_DATA_BYTE_MS      20    // ya en régimen de transferencia FIFO

#define TIMEOUT_STATUS_MS        500
#define TIMEOUT_MSGIN_MS         500

#define TIMEOUT_SPINUP_MS      20000    // espera de arranque de plato
                                          // (sin dato oficial: margen
                                          // generoso, ~15-20s típico en
                                          // Winchester de esta época)

#define MAX_RETRIES                 3

/* ---- Estado compartido con la ISR (todo volatile) --------------------- */
static volatile uint8_t  *xfer_buf;
static volatile uint16_t  xfer_len;
static volatile uint16_t  xfer_idx;
static volatile uint8_t   xfer_dir;
static volatile bool      phase_done;
static volatile uint32_t  last_activity_ms;   // actualizado por la ISR en
                                                // cada flanco de REQ; el
                                                // main loop lo usa para
                                                // detectar bus colgado

/* =====================================================================
 * ISR: se dispara en AMBOS flancos de REQ (CHANGE).
 * Un ciclo de byte = flanco de subida (REQ asserted) + flanco de
 * bajada (REQ deasserted). Esto reproduce exactamente el diagrama de
 * la sección 2, pero repartido en dos disparos de interrupción en
 * vez de dos "while" bloqueantes.
 * ===================================================================== */
void ISR_scsi_req_change(void) {
    last_activity_ms = millis();     // marca de tiempo para el watchdog

    if (digitalRead(PIN_REQ) == HIGH) {
        /* --- Flanco de subida: target listo para transferir un byte --- */
        if (xfer_dir == DIR_IN) {
            xfer_buf[xfer_idx] = DATA_PORT_READ();      // captura byte
        } else {
            DATA_DDR  = 0xFF;                            // bus como salida
            DATA_PORT_WRITE(xfer_buf[xfer_idx]);         // coloca byte
        }
        digitalWrite(PIN_ACK, HIGH);                     // ACK_assert()

    } else {
        /* --- Flanco de bajada: target ya latcheó / retiró el dato --- */
        if (xfer_dir == DIR_OUT) {
            DATA_DDR = 0x00;                              // suelta el bus
        }
        digitalWrite(PIN_ACK, LOW);                       // ACK_deassert()

        xfer_idx++;
        if (xfer_idx >= xfer_len) {
            phase_done = true;      // el main loop lo detecta y avanza
        }
    }
}

typedef enum { RP_OK, RP_TIMEOUT_SEEK, RP_TIMEOUT_BUS } run_phase_result_t;
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

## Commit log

2026-07-16 update 2
    [QL_CST_SCSI.kicad_sch]
2026-09-22 small update
    [QL_CST_SCSI.kicad_pcb, QL_CST_SCSI.kicad_sch]

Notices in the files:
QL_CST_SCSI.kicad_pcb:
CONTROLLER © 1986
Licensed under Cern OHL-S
